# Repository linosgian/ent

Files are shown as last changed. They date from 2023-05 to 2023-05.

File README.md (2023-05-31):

# Ent

## Ergogen generated split keyboard

This fork of [ergogen](https://github.com/linosgian/ergogen/tree/lgian/custom_footprints) is used, which contains all the custom footprints that appear on the board (holes, trackpad, elite-c etc)

left | right
-|-
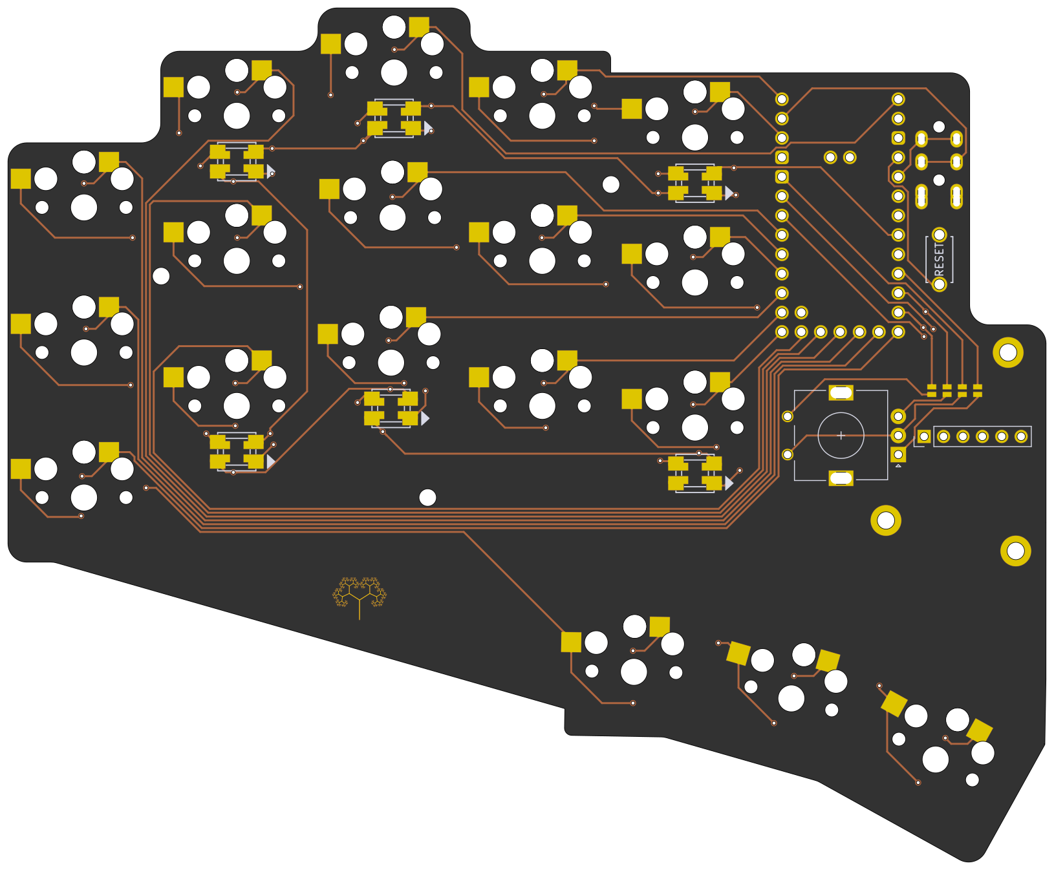
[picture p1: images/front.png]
left
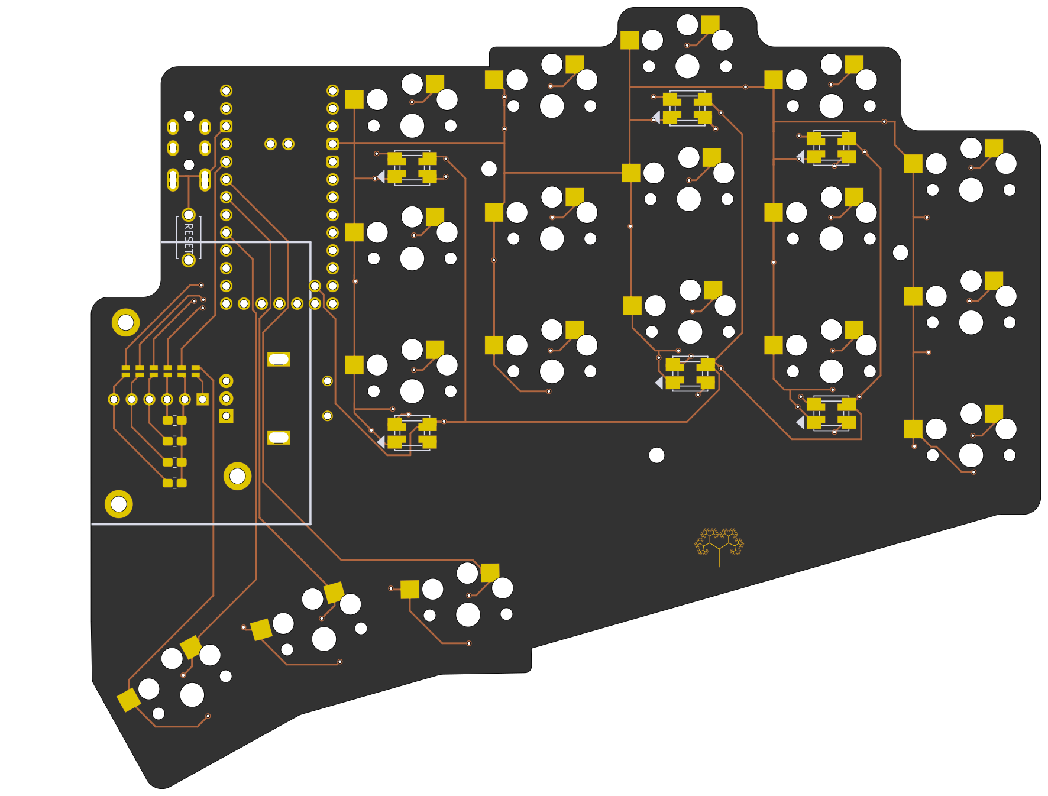
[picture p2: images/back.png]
right
 | 

## Features

* Support for a [cirque](https://keycapsss.com/keyboard-parts/parts/211/glidepoint-cirque-trackpad-tm040040-tm035035?c=11) and [Azoteq](https://keycapsss.com/keyboard-parts/parts/247/azoteq-proxsense-i2c-touch-sensor-module/capacitive-trackpad) trackpads on the right side (solderable jumpers)
* Support for a rotary encoder on the left side (solderable jumpers)
* Uses elite-c (or equivalent like puchi-c) so more io pins are available
* No diodes (less complexity during soldering)
* Reversible
* Only supports choc v1

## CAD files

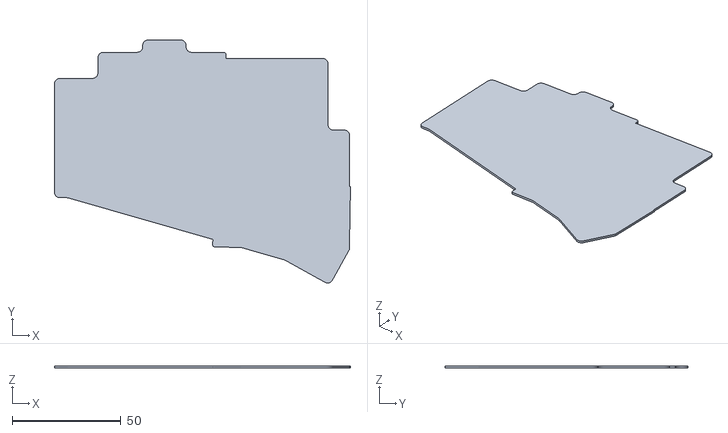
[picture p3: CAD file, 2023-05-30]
cases/bottom.stl
136.3 x 111.9 x 1.00

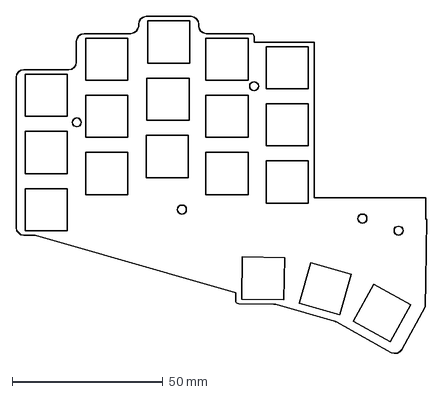
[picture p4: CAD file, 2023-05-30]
outlines/switch_plate.dxf
136.3 x 112.3 mm

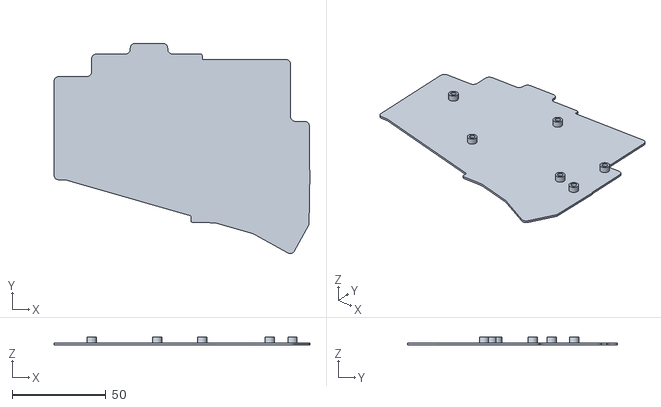
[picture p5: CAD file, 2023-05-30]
cases/case.stl
136.3 x 111.9 x 4.00

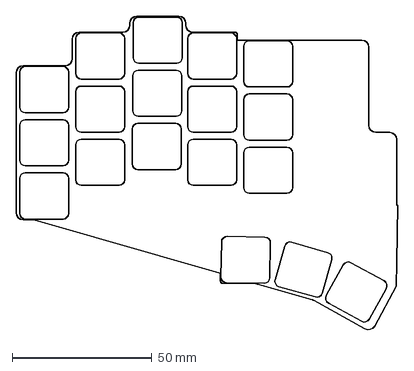
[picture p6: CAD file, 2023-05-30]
outlines/preview.dxf
136.3 x 112.3 mm

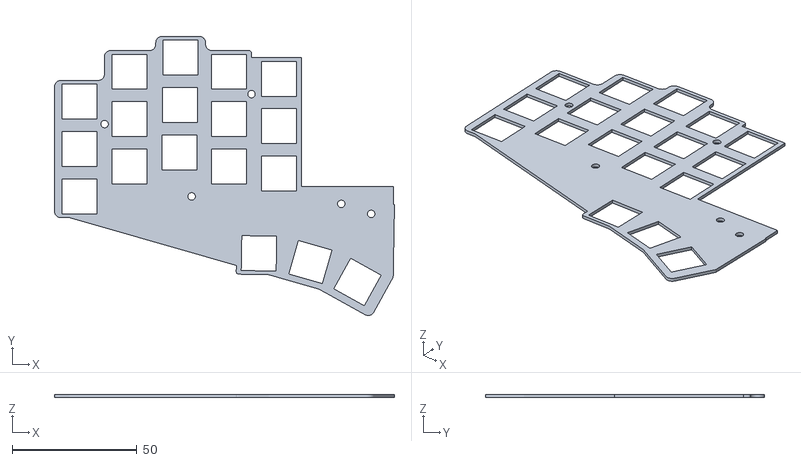
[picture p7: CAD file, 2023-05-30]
cases/switchplate.stl
136.3 x 111.9 x 1.20

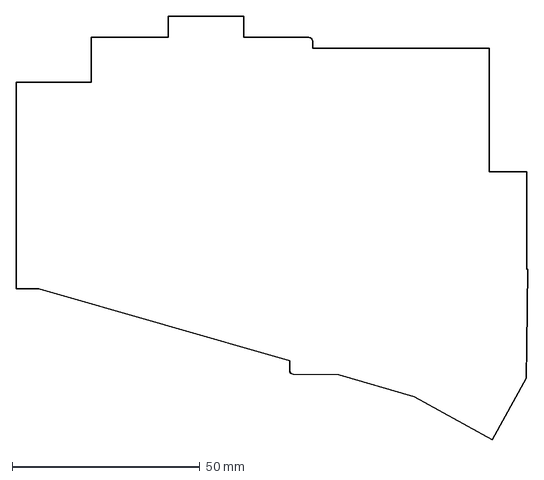
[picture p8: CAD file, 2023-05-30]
outlines/raw.dxf
136.3 x 112.8 mm

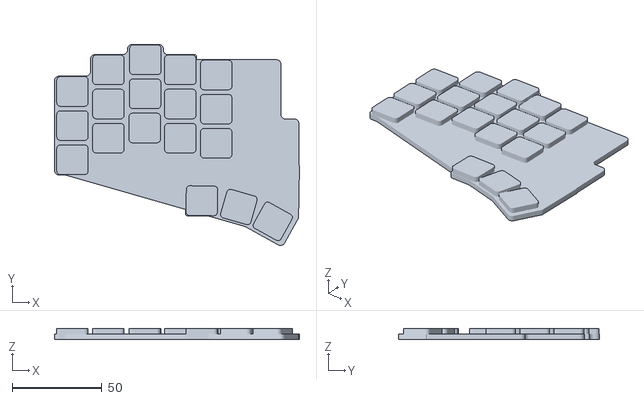
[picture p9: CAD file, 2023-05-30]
cases/preview.stl
136.3 x 111.9 x 6.00

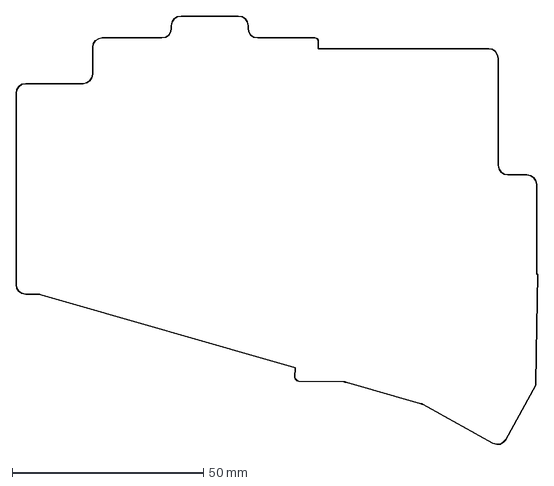
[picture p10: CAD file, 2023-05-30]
outlines/panel.dxf
136.3 x 112.3 mm

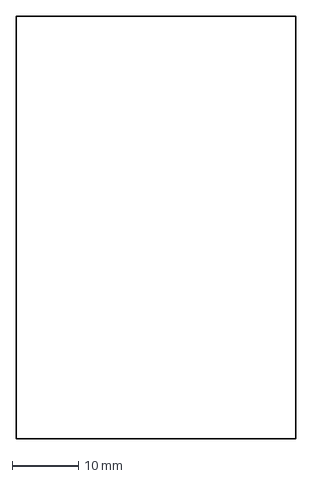
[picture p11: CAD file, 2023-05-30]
outlines/footprints.dxf
42.0 x 63.5 mm

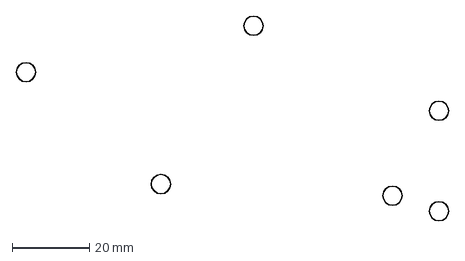
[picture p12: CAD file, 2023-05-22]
outlines/standoff.dxf
111.9 x 53.0 mm

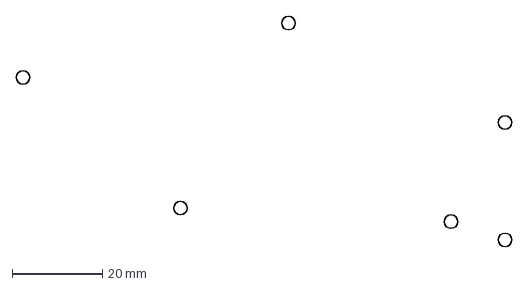
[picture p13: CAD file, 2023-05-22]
outlines/mounting.dxf
109.9 x 51.0 mm

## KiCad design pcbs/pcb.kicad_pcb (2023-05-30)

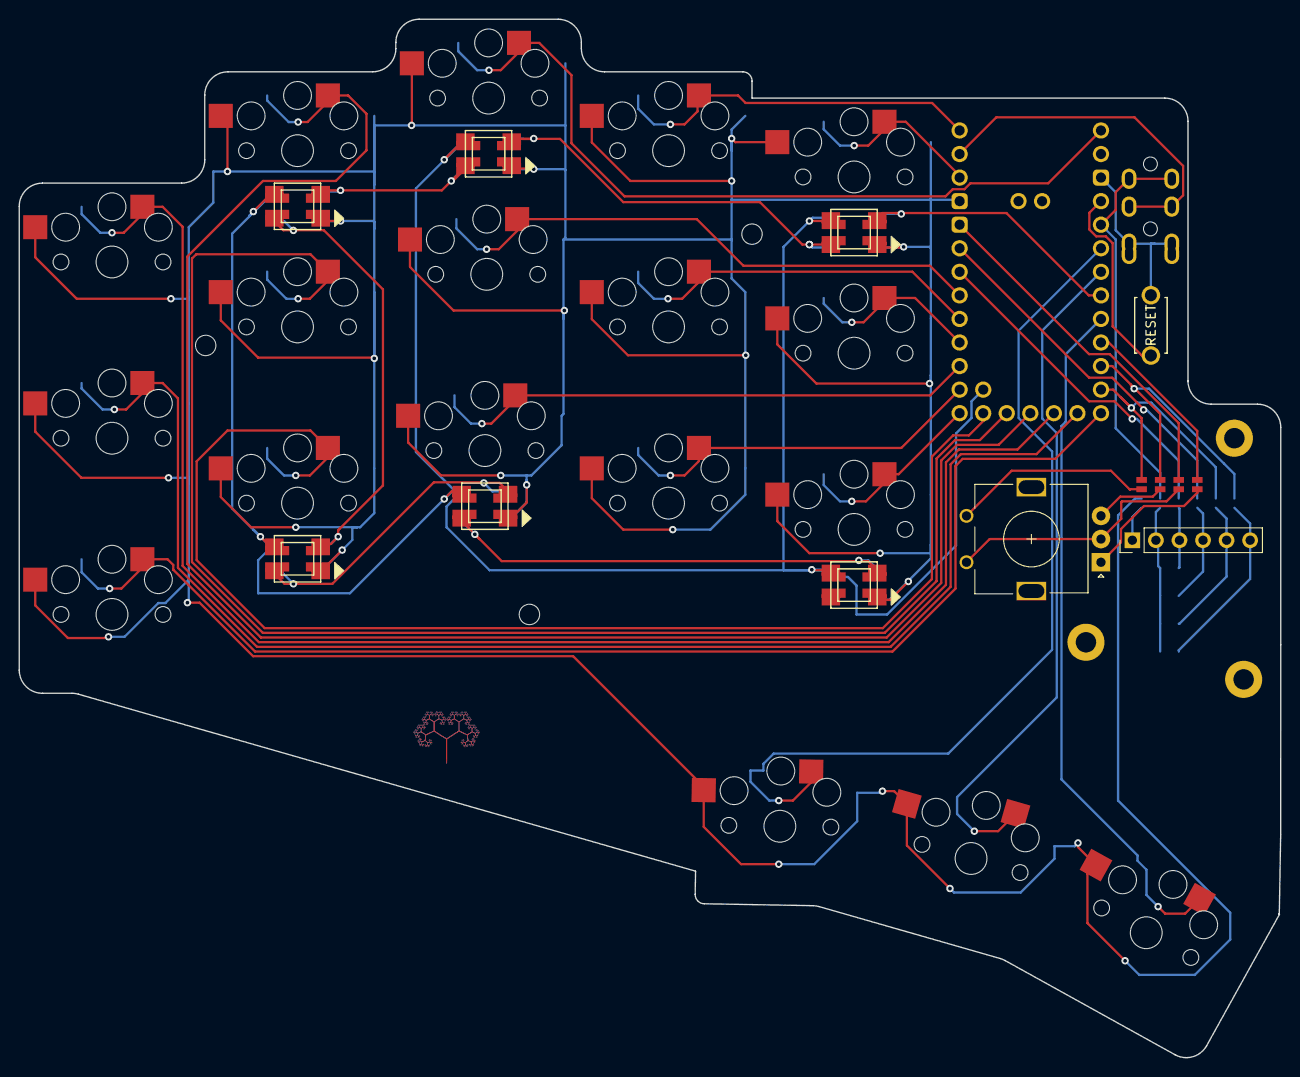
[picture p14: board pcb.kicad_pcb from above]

Board: 2 copper layers, 136.0 x 112.0 mm, 50 parts (0 on the bottom side), 39 nets.

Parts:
J1, J2, J3, J4, J5, J6, J7, J8, J9, J10: Jumper
LED1, LED2, LED3, LED4, LED5, LED6, LED7, LED8, LED9, LED10, LED11, LED12: WS2812B
MCU1: Elite-C; Helios
ROT1: rotary_encoder
S1, S2, S3, S4, S5, S6, S7, S8, S9, S10, S11, S12, S13, S14, S15, S16, S17, S18: PG1350
TRRS1: TRRS-PJ-320A-dual
_1: ResetSW
_2, _3, _4: MountingHole_2.2mm_M2_Pad_Via
_5, _6, _7: MountingHole_2.2mm_M2

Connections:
A0: MCU1.23, S18.1
A1: LED5.4, LED5.44, LED11.4, LED11.44, MCU1.24
A2: MCU1.25, S17.1
A3: MCU1.26, S16.1
GND: J3.2, J5.2, LED1.3, LED1.33, LED2.3, LED2.33, LED3.3, LED3.33, LED4.3, LED4.33, LED5.3, LED5.33, LED6.3, LED6.33, LED7.3, LED7.33, LED8.3, LED8.33, LED9.3, LED9.33, LED10.3, LED10.33, LED11.3, LED11.33, LED12.3, LED12.33, MCU1.4, MCU1.5, MCU1.29, S1.2, S2.2, S3.2, S4.2, S5.2, S6.2, S7.2, S8.2, S9.2, S10.2, S11.2, S12.2, S13.2, S14.2, S15.2, S16.2, S17.2, S18.2, TRRS1.1, TRRS1.2, _1.2
IO2: J8.2, MCU1.6
IO3: J7.2, MCU1.7
IO4: MCU1.8, S8.1
IO5: MCU1.9, S11.1
IO6: MCU1.10, S14.1
IO7: MCU1.11, S7.1
IO8: MCU1.12, S10.1
IO9: MCU1.13, S13.1
IO10: MCU1.1, S12.1
IO11: MCU1.31, S9.1
IO12: MCU1.14, S4.1
IO13: MCU1.15, S5.1
IO14: MCU1.16, S6.1
IO15: MCU1.17, S3.1
IO16: MCU1.18, S2.1
IO20: J2.2, J10.2, MCU1.21
IO21: MCU1.19, S1.1
IO22: J4.2, MCU1.22
IO23: J1.2, J9.2, MCU1.20
NAN: LED6.2, LED6.22, LED12.2, LED12.22
O2: J1.1, ROT1.2
O3: J4.1, ROT1.A
O4: J3.1, ROT1.1, ROT1.C
O5: J2.1, ROT1.B
RGB: LED1.1, LED1.11, LED2.1, LED2.11, LED3.1, LED3.11, LED4.1, LED4.11, LED5.1, LED5.11, LED6.1, LED6.11, LED7.1, LED7.11, LED8.1, LED8.11, LED9.1, LED9.11, LED10.1, LED10.11, LED11.1, LED11.11, LED12.1, LED12.11, MCU1.32
RGB1: LED3.4, LED3.44, LED5.2, LED5.22, LED9.4, LED9.44, LED11.2, LED11.22
RGB2: LED1.4, LED1.44, LED3.2, LED3.22, LED7.4, LED7.44, LED9.2, LED9.22
RGB3: LED1.2, LED1.22, LED2.4, LED2.44, LED7.2, LED7.22, LED8.4, LED8.44
RGB4: LED2.2, LED2.22, LED4.4, LED4.44, LED8.2, LED8.22, LED10.4, LED10.44
RGB5: LED4.2, LED4.22, LED6.4, LED6.44, LED10.2, LED10.22, LED12.4, LED12.44
RST: MCU1.28, _1.1
RX: MCU1.3, S15.1
TX: MCU1.2, TRRS1.3
VCC: J6.2, MCU1.27, TRRS1.4

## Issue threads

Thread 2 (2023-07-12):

Suggestions for v2

thanasis00, 2023-07-12:
After building this keyboard, we noticed a few things that could work better for the next revision.

1. TRRS jacks should be moved to the edge of the pcb, because now [some cables with thicker connector caps](https://github.com/linosgian/ent/assets/2803147/48bd2b20-db9c-4974-aa95-0f0d068a4250) cannot be connected
2. The mcu could be a little bit further from the keys, as it is now easy to press on the mcu instead of a key
3. Underglow LEDs (WS2812) on the left side should be rotated, as now the LED pad do not align with the pcb pads
4. A possible improvement could be that the pcb should have an integrated fpc connector for azoteq, so you can plug it with only a fpc cable.
5. Azoteq does not require the pullup resistors on the pcb, because RP2040 internal pullups are working perfectly.
6. Maybe the rotary and touchpad jumpers could be removed, as the goal of this keyboard is to always integrate them, and it will make the build easier as well

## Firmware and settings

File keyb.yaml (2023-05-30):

---
units:
  # Constants
  choc_cap_x: 17.5
  choc_cap_y: 16.5
  spread: 20

  screwSize: 1.5
  standoffSize: 2.5

  choc_plate_thickness: 1.2
  mx_plate_thickness: 1.5
points:
  zones:
    matrix:
      columns:
        pinky:
          key:
            origin: [0, -17]
            spread: spread
          rows:
            bottom:
              bind: [5, 0, 0, 1]
              column_net: IO21
            home:
              bind: [0, 12, 0, 1]
              column_net: IO16
            top:
              bind: [0, 8, 5, 1]
              column_net: IO15
        ring:
          key:
            spread: spread
            stagger: 12
            origin: [0, -17]
          rows:
            bottom:
              bind: [0, 0, 2, 10]
              column_net: IO12
            home:
              bind: [5, 0, 5, 0]
              column_net: IO13
            top:
              bind: [0, 6, 0, 1]
              column_net: IO14
        middle:
          key:
            shift: [0.2, 0]
            stagger: 17/3
            spread: spread
            origin: [0, -17]
          rows:
            bottom:
              bind: [0, 10, 15, 5]
              column_net: IO7
            home:
              bind: 5
              column_net: IO4
            top:
              bind: [0, 1, 0, 1]
              column_net: IO11
        index:
          key:
            stagger: -17/3
            origin: [0, -17]
            spread: spread
          rows:
            bottom:
              bind: [0, 5, 5, 0]
              column_net: IO8
            home:
              bind: [5, 0, 5, 0]
              column_net: IO5
            top:
              bind: [0, 0, 0, 6]
              column_net: IO10
        inner:
          key:
            stagger: -17/6
            origin: [0, -17]
            spread: spread
          rows:
            bottom:
              bind: [5, 37, 20, 2]
              column_net: IO9
            home:
              bind: [0, 27, 0, 5]
              column_net: IO6
            top:
              bind: [0, 27, 5, 5]
              column_net: RX
      rows:
        bottom:
          padding: 19
        home:
          padding: 19
        top:
    thumb:
      anchor:
        ref: matrix_inner_bottom
        shift: [-8, -32]
      columns:
        first:
          key:
            splay: -1
          rows:
            only:
              column_net: A3
              bind: [12, 45, 0, 0]
        second:
          key:
            spread: 17
            splay: -15
            origin: [-10, -15.5]
          rows:
            only:
              column_net: A2
              bind: [10, 0, 1, 90]
        third:
          key:
            rotate: -30
            spread: 17
            splay: 17
            origin: [10, 10]
          rows:
            only:
              column_net: A0
              bind: [0.2, 2.6, 1.5, 10]
      rows:
        only:
          padding: 17
      key:
        footprints:
cases:
  _holes:
    - name: mounting
      extrude: 4
  _standoffs:
    - name: standoff
      extrude: 4
  bottom:
    - what: outline
      name: panel
      extrude: 1
  switchplate:
    - what: outline
      name: switch_plate
      extrude: choc_plate_thickness
  case:
    - what: case
      name: _standoffs
      operation: add
    - what: case
      name: _holes
      operation: subtract
    - what: case
      name: bottom
      operation: add
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

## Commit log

2023-05-13 Add logo footprints
2023-05-14 Move a few IO pins around to enable I2C and TRRS communication
    Previously the wrong pins were used so TRRS and I2C (for cirque)
    wouldn't work. Thanks to (0), I didn't print the previous version of the
    board because nothing would work essentially.
    (0): https://www.reddit.com/r/ErgoMechKeyboards/comments/13ftrsc/comment/jjwuh69/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
    [pcb.kicad_pcb, pcb_back.kicad_pcb]
2023-05-16 Finalize routing and logo
    [pcb-B_Cu.gbr, pcb-B_Mask.gbr, pcb-B_Paste.gbr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]
2023-05-17 Change logo
    [pcb-B_Cu.gbr, pcb-B_Mask.gbr, pcb-B_Paste.gbr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]
2023-05-17 Update pcbdraw rendered images
2023-05-17 Add 3D printable bottom case with screw standoffs
2023-05-20 Convert to Helios (RP2040-based) MCU and add underglow LEDs
    [pcb.kicad_pcb]
2023-05-20 Fix via overlapping with pad
    [pcb.kicad_pcb]
2023-05-20 Re-generate gerber files
    [pcb-B_Cu.gbr, pcb-B_Mask.gbr, pcb-B_Paste.gbr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]
2023-05-21 Connect LEDs' VDD pin to Helios' RGB pin for stable 5V
    [pcb-B_Cu.gbr, pcb-B_Mask.gbr, pcb-B_Paste.gbr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]
2023-05-22 Update outlines and cases
    [case.stl, mounting.dxf, standoff.dxf]
2023-05-22 Add switchplane stl
    [switchplate.stl]
2023-05-23 Move thumb cluster to the left by half a (choc) switch
    [bottom.stl, case.stl, footprints.dxf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]
2023-05-23 Reduce spread between keys in thumb cluster
    [bottom.stl, case.stl, panel.dxf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]
2023-05-24 Fix thumb cluster spacing
    [bottom.stl, case.stl, panel.dxf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]
2023-05-30 Remove pcb-backups
2023-05-30 Add support for azoteq TPS43 while maintaining support for cirque
    [bottom.stl, case.stl, footprints.dxf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]
2023-05-30 Re-run gerber file generation
    [pcb-B_Cu.gbr, pcb-B_Mask.gbr, pcb-B_Paste.gbr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]
